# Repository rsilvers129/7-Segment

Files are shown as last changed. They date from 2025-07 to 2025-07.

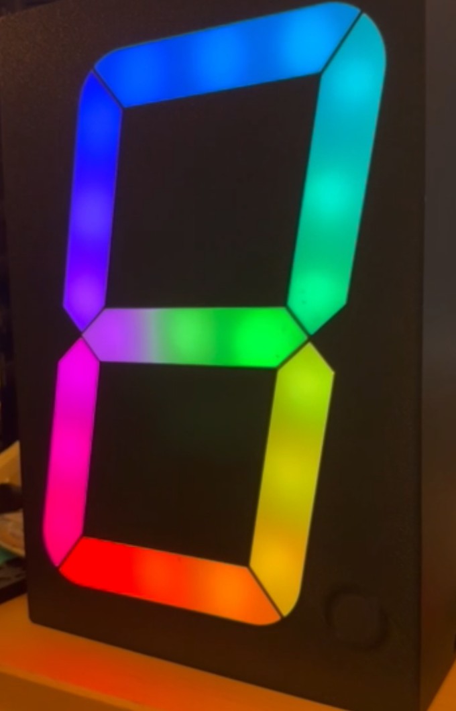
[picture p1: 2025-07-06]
rainbow.jpg

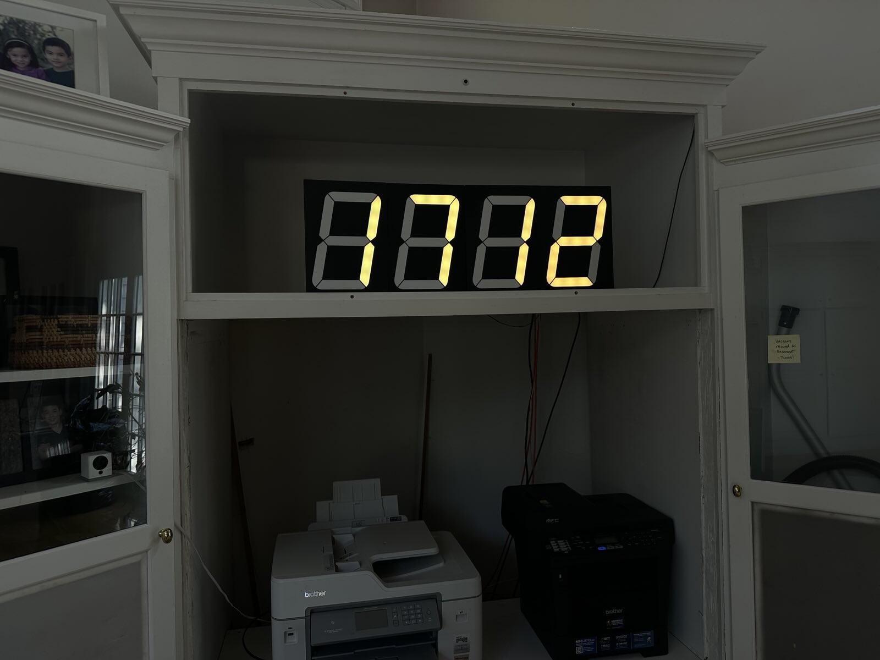
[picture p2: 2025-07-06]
IMG_0563.jpg

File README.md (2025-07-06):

# 7-Segment
Custom large display for clock or timer

This is on MakerWorld at: https://makerworld.com/en/models/1581853-yuge-7-segment-display-1290mm-50-8-wide-clock#profileId-1664897

Make a massive 50.8" wide clock on your H2D, or 40.6" on your standard-size printer.

Use 4 segments for HH:MM or 6 for HH:MM:SS. Prints with 2-colors in place with no support. 

Recommended parts:

Power Supply: https://www.amazon.com/dp/B0C1ZVW7B9?ref=ppx_yo2ov_dt_b_fed_asin_title
 
ESP32 with Breakout Board (just need one of them): https://www.amazon.com/dp/B0DPS44HCQ

Buttons (need two): https://www.amazon.com/dp/B01E38OS7K

5v WS2811 LED strings (21 per segment): https://tinyurl.com/5y28k6ad

Optional magnets to help hold them in alignment (or you can glue them): https://www.amazon.com/dp/B09WRF51KY

Some extra wire, and possibly 3-pin connectors made for LED strings.

Note: I have also included a model with a decimal in case you want it for another purpose. 

One button cycles through 5 brightness levels (ESP32 PIN 14), the other one cycles color modes (ESP32 PIN 27). There are 33 color modes, plus three auto-cycle modes. The first auto-cycle mode (when you see a white flash) changes the mode once per second. The second auto mode does it once per minute. The third does it once per hour. Mode is saved in EEPROM in case of power loss.

Build the code in Arduino IDE. Use ESP32 Dev Module as the board type, need to hold down the boot button when loading the code. Need libraries: Adafruit NeoPixel 1.15.1, and WiFi Manager 2.0.17 by tzapu.

Adjust for your time-zone.

Has WiFi to sync every hour (use phone to connect to the clock to provide your WiFi password).

You can slide the breakout board into the slot at the bottom, or use M3 heat-set inserts if you want to mount it on the mount area that only the larger model has.

You can design and print clamps to hold the digital together if you don't want to glue them, or use cheap Harbor-Freight plastic clamps.

Connect LED string to PIN 13.

Plug in LEDs as per my photo, and wire from the end of one string to the beginning of the next.

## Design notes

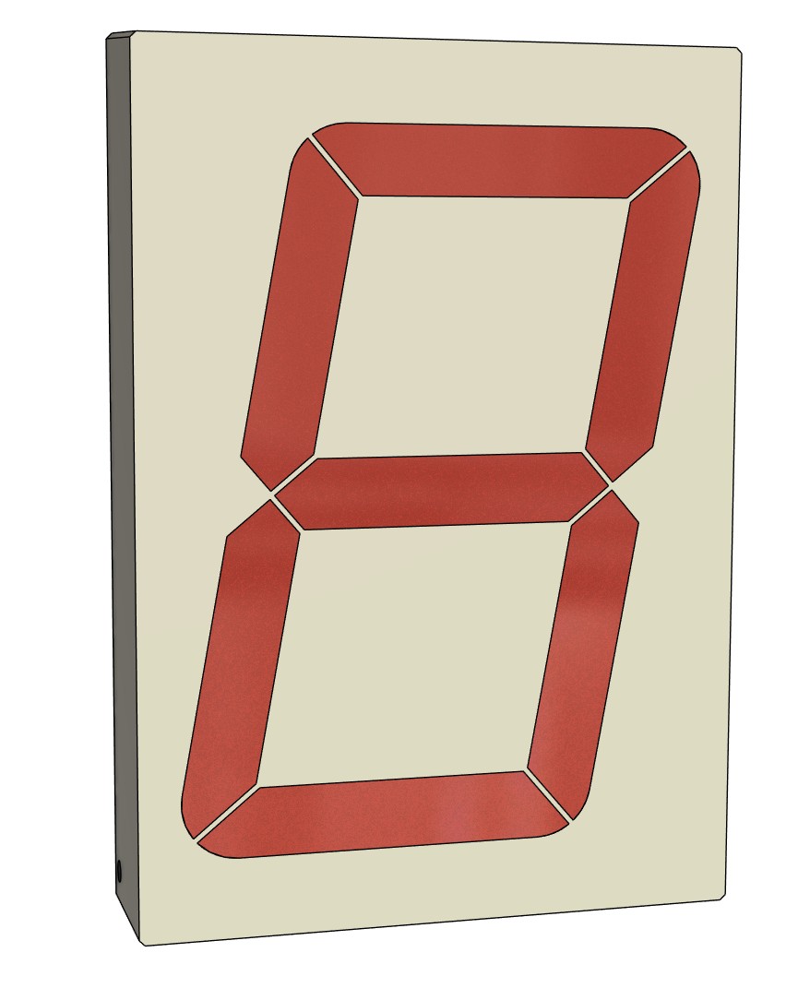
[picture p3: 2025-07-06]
front.jpg

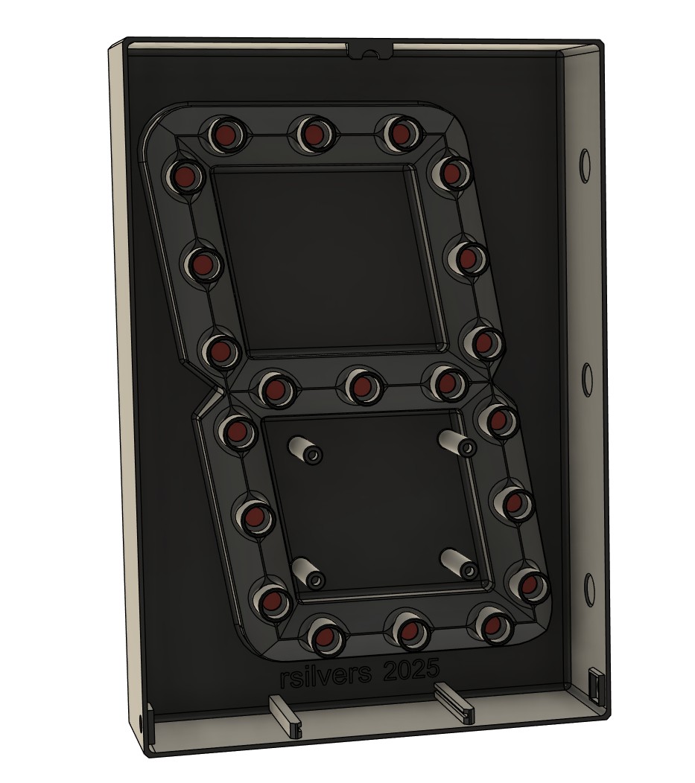
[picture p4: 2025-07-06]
rear.jpg

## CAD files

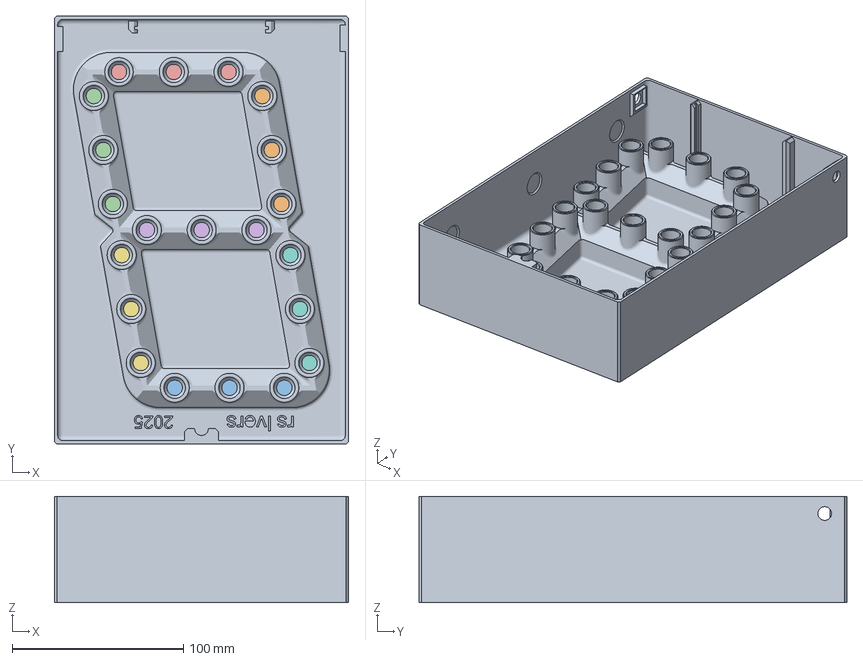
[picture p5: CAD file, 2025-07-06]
Segment v50-Standard.3mf
172.0 x 250.0 x 62.0 mm
Segment 250mm v36_1
Segment 250mm v36_2
Segment 250mm v36_3
Segment 250mm v36_4
Segment 250mm v36_5
Segment 250mm v36_6
Segment 250mm v36_7
Segment 250mm v36_8

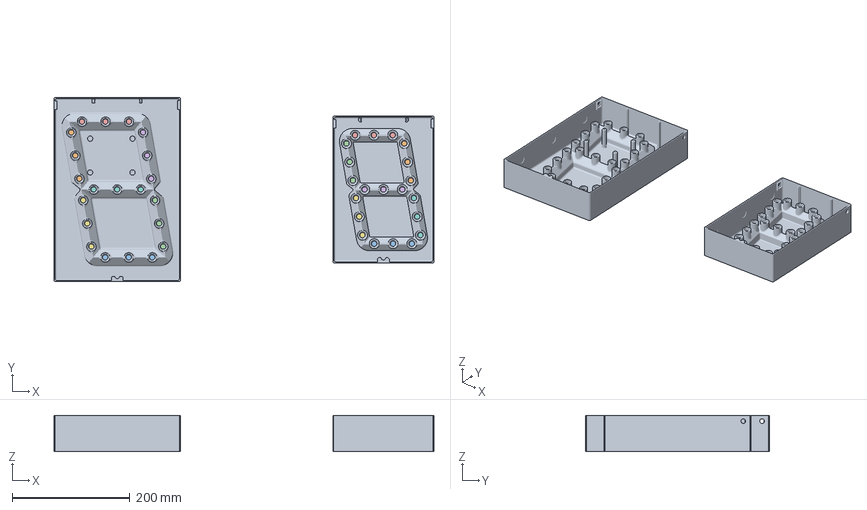
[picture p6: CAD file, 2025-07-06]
Segment v50-H2D.3mf
646.2 x 313.6 x 62.0 mm
Segment 250mm v36_1
Segment 250mm v36_2
Segment 250mm v36_3
Segment 250mm v36_4
Segment 250mm v36_5
Segment 250mm v36_6
Segment 250mm v36_7
Segment 250mm v36_8
Segment H2D v26_1
Segment H2D v26_2
Segment H2D v26_3
Segment H2D v26_4
Segment H2D v26_5
Segment H2D v26_6
Segment H2D v26_7
Segment H2D v26_8

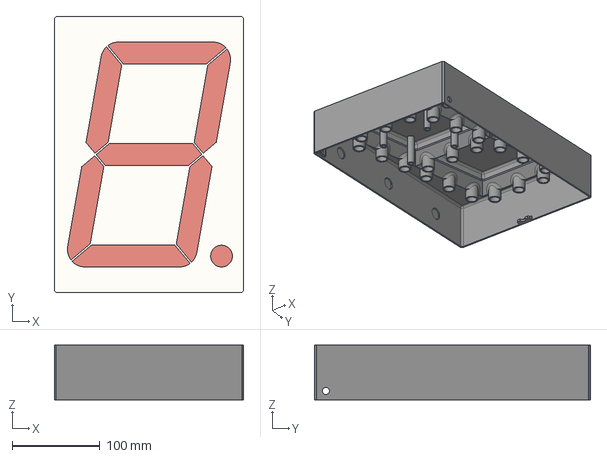
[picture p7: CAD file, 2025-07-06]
Segment H2D v26-WithDecimal.step
215.1 x 313.6 x 62.0 mm

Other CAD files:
Segment 250mm v36-WithDecimal.step
Segment 250mm v36.step
Segment H2D v26.step
Segment 250mm v36.f3d
Segment 250mm v36.stl
Segment H2D v26.f3d
Segment H2D v26.stl

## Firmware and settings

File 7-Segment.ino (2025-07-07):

/******************************************************************
 *  6-digit WS2811 24-hour clock — Robert Silvers, July 2025
 *
 *  • Wi-Fi via captive portal  (SSID CLOCK_xxxxxx)
 *  • Hourly NTP sync
 *  • Push-button (pin 27) cycles 36 colour modes (saved to EEPROM)
 *        0-6   = solid colours   (Red → White)
 *        7-31  = patterned modes (C/R/C … Y/R/Y)
 *        32    = Rainbow spectrum per digit
 *        33    = Auto-1 s   (cycle 0-32 once per second)
 *        34    = Auto-1 m   (cycle 0-32 once per minute)
 *        35    = Auto-1 h   (cycle 0-32 once per hour)
 *  • Second button (pin 14) cycles 5 brightness levels, incl. OFF
 *  • Centre LED shows Wi-Fi status (purple → yellow → white / red / blue)
 *  • Displays real HH:MM:SS
 ******************************************************************/

// ───── libraries ─────
#include <WiFiManager.h>        // 2.0.17
#include <Adafruit_NeoPixel.h>  // 1.15.1
#include <EEPROM.h>
#include <time.h>

// ───── hardware setup ─────
#define LED_PIN      13
#define BUTTON_PIN   27      // mode
#define BRIGHT_PIN   14      // brightness
#define NUM_LEDS     126
#define EEPROM_SIZE  8
#define MODE_ADDR    0
#define BRIGHT_ADDR  4

Adafruit_NeoPixel strip(NUM_LEDS, LED_PIN, NEO_GRB + NEO_KHZ800);

// ───── brightness table ─────
int brightnessLevels[] = {255,128,64,16,0};
const int NUM_BRIGHTNESS = sizeof(brightnessLevels)/sizeof(brightnessLevels[0]);
int currentBrightnessIndex = 0;

// ───── digit / segment map ─────
const uint8_t seg[7][3] = {
  {11,12,13},{ 8, 9,10},{ 3, 4, 5},
  { 0, 1, 2},{18,19,20},{14,15,16},{17, 6, 7}
};
const uint8_t CENTRE_LED = seg[6][1];

// segment masks 0-9
const bool digitMask[10][7] = {
  {1,1,1,1,1,1,0},{0,1,1,0,0,0,0},{1,1,0,1,1,0,1},{1,1,1,1,0,0,1},
  {0,1,1,0,0,1,1},{1,0,1,1,0,1,1},{1,0,1,1,1,1,1},{1,1,1,0,0,0,0},
  {1,1,1,1,1,1,1},{1,1,1,1,0,1,1}
};

// ───── colour tables ─────
const uint32_t baseColors[] = {
  strip.Color(  0,255,  0), // Red   (GRB)
  strip.Color(255,  0,  0), // Green
  strip.Color(  0,  0,255), // Blue
  strip.Color(255,255,  0), // Yellow
  strip.Color(255,  0,255), // Magenta
  strip.Color(  0,255,255), // Cyan
  strip.Color(255,255,255)  // White
};
const char* baseNames[] = {"Red","Green","Blue","Yellow","Magenta","Cyan","White"};
const int numBase = sizeof(baseColors)/sizeof(baseColors[0]);

struct Pattern { const char* name; uint32_t L,C,R; };
const Pattern patternModes[] = {
  {"C/R/C", strip.Color(  0,255,255), strip.Color(  0,255,  0), strip.Color(  0,255,255)},
  {"R/C/R", strip.Color(  0,255,  0), strip.Color(  0,255,255), strip.Color(  0,255,  0)},
  {"G/M/G", strip.Color(255,  0,255), strip.Color(255,  0,  0), strip.Color(255,  0,255)},
  {"M/G/M", strip.Color(255,  0,  0), strip.Color(255,  0,255), strip.Color(255,  0,  0)},
  {"O/B/O", strip.Color(  0,  0,255), strip.Color(255,128,  0), strip.Color(  0,  0,255)},
  {"B/O/B", strip.Color(255,128,  0), strip.Color(  0,  0,255), strip.Color(255,128,  0)},
  {"DB/LB/DB",strip.Color(  0,  0,128), strip.Color(128,128,255), strip.Color(  0,  0,128)},
  {"LB/DB/LB",strip.Color(128,128,255), strip.Color(  0,  0,128), strip.Color(128,128,255)},
  {"DR/O/DR",strip.Color(128,  0,  0), strip.Color(255,128,  0), strip.Color(128,  0,  0)},
  {"O/DR/O", strip.Color(255,128,  0), strip.Color(128,  0,  0), strip.Color(255,128,  0)},
  {"DG/LG/DG",strip.Color(  0,128,  0), strip.Color(128,255,128), strip.Color(  0,128,  0)},
  {"LG/DG/LG",strip.Color(128,255,128), strip.Color(  0,128,  0), strip.Color(128,255,128)},
  {"P/C/P", strip.Color(255,  0,255), strip.Color(  0,255,255), strip.Color(255,  0,255)},
  {"C/P/C", strip.Color(  0,255,255), strip.Color(255,  0,255), strip.Color(  0,255,255)},
  {"W/B/W", strip.Color(255,255,255), strip.Color(  0,  0,255), strip.Color(255,255,255)},
  {"B/W/B", strip.Color(  0,  0,255), strip.Color(255,255,255), strip.Color(  0,  0,255)},
  {"Y/P/Y", strip.Color(255,255,  0), strip.Color(255,  0,255), strip.Color(255,255,  0)},
  {"P/Y/P", strip.Color(255,  0,255), strip.Color(255,255,  0), strip.Color(255,  0,255)},
  {"B/R/B", strip.Color(  0,  0,255), strip.Color(  0,255,  0), strip.Color(  0,  0,255)},
  {"R/B/R", strip.Color(  0,255,  0), strip.Color(  0,  0,255), strip.Color(  0,255,  0)},
  {"B/R/B", strip.Color(  0,  0,255), strip.Color(  0,255,  0), strip.Color(  0,  0,255)},
  {"Y/B/Y", strip.Color(255,255,  0), strip.Color(  0,  0,255), strip.Color(255,255,  0)},
  {"B/Y/B", strip.Color(  0,  0,255), strip.Color(255,255,  0), strip.Color(  0,  0,255)},
  {"R/Y/R", strip.Color(  0,255,  0), strip.Color(255,255,  0), strip.Color(  0,255,  0)},
  {"Y/R/Y", strip.Color(255,255,  0), strip.Color(  0,255,  0), strip.Color(255,255,  0)}
};
const int numPatterns = sizeof(patternModes)/sizeof(patternModes[0]);

// ───── mode indices ─────
const int RAINBOW_MODE = numBase + numPatterns;  // 32
const int AUTO_1S_MODE = RAINBOW_MODE + 1;       // 33
const int AUTO_1M_MODE = AUTO_1S_MODE + 1;       // 34
const int AUTO_1H_MODE = AUTO_1M_MODE + 1;       // 35
const int TOTAL_MODES  = AUTO_1H_MODE + 1;       // 36

// ───── Wi-Fi colours ─────
const uint32_t PURPLE = strip.Color(  0,255,255);
const uint32_t YELLOW = strip.Color(255,255,  0);
const uint32_t WHITE  = strip.Color(255,150,150);
const uint32_t REDLED = strip.Color(  0,255,  0);
const uint32_t BLUELED= strip.Color(  0,  0,255);

// ───── time / Wi-Fi ─────
const char* TZ   = "EST5EDT,M3.2.0/2,M11.1.0/2";
time_t lastSync  = 0;
int    currentMode=0;

// ───── helpers ─────
void setStatusLED(uint32_t c){ strip.setPixelColor(CENTRE_LED,c); strip.show(); }
uint32_t rainbowColor(uint8_t i){ uint16_t h=(uint32_t)i*65535/21; return strip.ColorHSV(h,255,255); }

// ───── Wi-Fi ─────
void connectWiFi(){
  setStatusLED(PURPLE); delay(500);
  WiFiManager wm;
  String id = String((uint32_t)(ESP.getEfuseMac()>>32),HEX);
  if(!wm.autoConnect(("CLOCK_"+id).c_str())){
    setStatusLED(BLUELED); wm.startConfigPortal(("CLOCK_"+id).c_str());
  }
  setStatusLED(WHITE);
}
void syncTime(){ configTzTime(TZ,"pool.ntp.org","time.nist.gov"); while(time(nullptr)<1609459200) delay(200); lastSync=time(nullptr); }

// ───── drawing ─────
void drawDigit(uint8_t pos,uint8_t val,int mode,int sec){
  uint8_t off=pos*21;
  for(uint8_t s=0;s<7;++s){
    if(!digitMask[val][s]) continue;
    if(mode==RAINBOW_MODE){
      for(uint8_t j=0;j<3;++j) strip.setPixelColor(off+seg[s][j], rainbowColor(seg[s][j]));
      continue;
    }
    uint32_t l,c,r;
    if     (mode < numBase)       l=c=r=baseColors[mode];
    else if(mode < RAINBOW_MODE){ const Pattern& p=patternModes[mode-numBase]; l=p.L; c=p.C; r=p.R; }
    else                          l=c=r=baseColors[(sec/10)%numBase];
    strip.setPixelColor(off+seg[s][0],l);
    strip.setPixelColor(off+seg[s][1],c);
    strip.setPixelColor(off+seg[s][2],r);
  }
}
void showTime(struct tm& t,int mode){
  strip.clear();
  drawDigit(0,t.tm_hour/10,mode,t.tm_sec);
  drawDigit(1,t.tm_hour%10,mode,t.tm_sec);
  drawDigit(2,t.tm_min /10,mode,t.tm_sec);
  drawDigit(3,t.tm_min %10,mode,t.tm_sec);
  drawDigit(4,t.tm_sec /10,mode,t.tm_sec);
  drawDigit(5,t.tm_sec %10,mode,t.tm_sec);
  strip.show();
}
String modeName(int m){
  if(m<numBase)              return baseNames[m];
  if(m<RAINBOW_MODE)         return patternModes[m-numBase].name;
  if(m==RAINBOW_MODE)        return "Rainbow";
  if(m==AUTO_1S_MODE)        return "Auto-1 s";
  if(m==AUTO_1M_MODE)        return "Auto-1 m";
  if(m==AUTO_1H_MODE)        return "Auto-1 h";
  return "?";
}

// ───── setup ─────
void setup(){
  Serial.begin(115200);
  pinMode(BUTTON_PIN ,INPUT_PULLUP);
  pinMode(BRIGHT_PIN ,INPUT_PULLUP);
  strip.begin(); delay(10);

  EEPROM.begin(EEPROM_SIZE);
  EEPROM.get(MODE_ADDR   ,currentMode);
  EEPROM.get(BRIGHT_ADDR ,currentBrightnessIndex);
  if(currentMode<0||currentMode>=TOTAL_MODES){ currentMode=0; EEPROM.put(MODE_ADDR,currentMode); }
  if(currentBrightnessIndex<0||currentBrightnessIndex>=NUM_BRIGHTNESS){ currentBrightnessIndex=0; EEPROM.put(BRIGHT_ADDR,currentBrightnessIndex); }
  EEPROM.commit();
  strip.setBrightness(brightnessLevels[currentBrightnessIndex]);

  connectWiFi(); if(WiFi.status()==WL_CONNECTED) syncTime();

  time_t now=time(nullptr); struct tm t; localtime_r(&now,&t);
  Serial.printf("Start mode %d – %s\\n",currentMode,modeName(currentMode).c_str());
  showTime(t,currentMode);
}

// ───── loop ─────
void loop(){
  static bool wasModeBtn=false, wasBrightBtn=false;
  static int  lastSec=-1, lastMin=-1;
  static int  autoIdx=0;
  static time_t lastAutoTime=0;

  bool modeBtn = !digitalRead(BUTTON_PIN);
  if(modeBtn && !wasModeBtn){
    delay(50);
    if(!digitalRead(BUTTON_PIN)){
      while(!digitalRead(BUTTON_PIN)) delay(10);
      wasModeBtn=true;
      currentMode = (currentMode+1)%TOTAL_MODES;
      EEPROM.put(MODE_ADDR,currentMode); EEPROM.commit();
      Serial.printf("Mode → %d – %s\n",currentMode,modeName(currentMode).c_str());

      if(currentMode==AUTO_1S_MODE || currentMode==AUTO_1M_MODE || currentMode==AUTO_1H_MODE){
        for(int i=0;i<NUM_LEDS;++i) strip.setPixelColor(i,0xFFFFFF);
        strip.show(); delay(100); strip.clear(); strip.show();
        autoIdx=0; lastAutoTime=time(nullptr);
      }

      time_t n=time(nullptr); struct tm t; localtime_r(&n,&t);
      showTime(t,currentMode);
    }
  } else if(!modeBtn) wasModeBtn=false;

  bool brightBtn = !digitalRead(BRIGHT_PIN);
  if(brightBtn && !wasBrightBtn){
    delay(50);
    if(!digitalRead(BRIGHT_PIN)){
      while(!digitalRead(BRIGHT_PIN)) delay(10);
      wasBrightBtn=true;
      currentBrightnessIndex=(currentBrightnessIndex+1)%NUM_BRIGHTNESS;
      strip.setBrightness(brightnessLevels[currentBrightnessIndex]);
      EEPROM.put(BRIGHT_ADDR,currentBrightnessIndex); EEPROM.commit();
      Serial.printf("Brightness → %d\n",brightnessLevels[currentBrightnessIndex]);
      time_t n=time(nullptr); struct tm t; localtime_r(&n,&t); showTime(t,currentMode);
    }
  } else if(!brightBtn) wasBrightBtn=false;

  time_t now=time(nullptr); struct tm t; localtime_r(&now,&t);
  if(currentMode<=RAINBOW_MODE && t.tm_sec!=lastSec){
    lastSec=t.tm_sec; showTime(t,currentMode);
  }

  int interval = 0;
  if(currentMode==AUTO_1S_MODE) interval=1;
  else if(currentMode==AUTO_1M_MODE) interval=60;
  else if(currentMode==AUTO_1H_MODE) interval=3600;

  if(interval){
    if(now - lastAutoTime >= interval){
      lastAutoTime = now;
      autoIdx = (autoIdx+1)%AUTO_MODE_1;
      Serial.printf("Auto-cycle → %d – %s\n",autoIdx,modeName(autoIdx).c_str());
      showTime(t,autoIdx);
    }
  }

  if(WiFi.status()==WL_CONNECTED && now-lastSync>=3600) syncTime();
}
